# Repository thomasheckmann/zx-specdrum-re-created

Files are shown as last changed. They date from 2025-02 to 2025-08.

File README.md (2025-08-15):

# zx-specdrum-re-created
Recreated and improved version of [Currah SpecDrum](https://spectrumcomputing.co.uk/entry/1000062/Hardware/Cheetah_SpecDrum) Interface for ZX Spectrum

Work on this was initiated because existing schema found on the internet is with errors.

# Version 1
First version is more or less a 1:1 copy of the original interface. With help I got the correct values and type for all the Capacitors. Thanks to Matthew Logue for providing the information from his original interfaces, helping out with how to use the old software as well as doing a test build of the interface.

The only changes compared with original:
* PCB made more compact to fit into my ZX-Bus-Extender board, you can use a normal edge connecter if you prefer.
* Some components moved, all ICs now have the same orientation.
* Make sure all ICs have decoupling capacitors.
* Added a 3.5" mini-jack plug for audio out.

BOM:

## This is how version 1 turned out
| <!---> | <!---> |
| --- | --- |
|||

And it sounds like this in action https://youtube.com/shorts/cKAM5VnGr6U?feature=share

# Version 2
This update fixes a few errors from the initial release and introduces an option for sound enhancement:

* bypassed the anti-aliasing filter and somewhat improved the bass response
* option to switch between original or improved output (using jumper)
* C7 - changed from Ceramic 1uF to Electrolytic 10uF

BOM (recommended order):
* 4 x 6,2K Resistor
* 2 x 10,0K Resistor
* 2 x 100K Resistor
* 1 x 390R Resistor
* 1 x 680R Resistor
* 1 x 390K Resistor

* 3 x 100nF - MLC Capacitor P2,54
* 1 x 1nF - Ceramic Capacitor P2,54

* 1 x 2,7nF - Ceramic Capacitor P2,54
* 1 x 2,2nF - Ceramic Capacitor P2,54
* 1 x 82pF - Ceramic NPO P5,08

* 3 x 1uF - Tantal P5,08
* 1 x 22uF - Electrolyte Capacitor P2,54
* 1 x 10uF - Electrolyte Capacitor P2,54

* 1 x 74LS32
* 1 x TL084
* 1 x ZN428E-8
* 3.5 mono jack [like this](https://elektronik-lavpris.dk/p136328/pj-211-35mm-mono-jack-chassis-med-afbryder-switch/)

The sound improvement modification was suggested by D.A. Wilson of Hideaway Studio and is used here with permission. You can read about the mod [here](https://spectrumcomputing.co.uk/forums/viewtopic.php?t=4845)

## Version v1.2
[Hear the interface](https://youtube.com/shorts/OHfJIYJJYTI) in action here, playing a demo from the original [software](https://spectrumcomputing.co.uk/entry/8720/ZX-Spectrum/SpecDrum)

| <!---> | <!---> |
| --- | --- |
|||

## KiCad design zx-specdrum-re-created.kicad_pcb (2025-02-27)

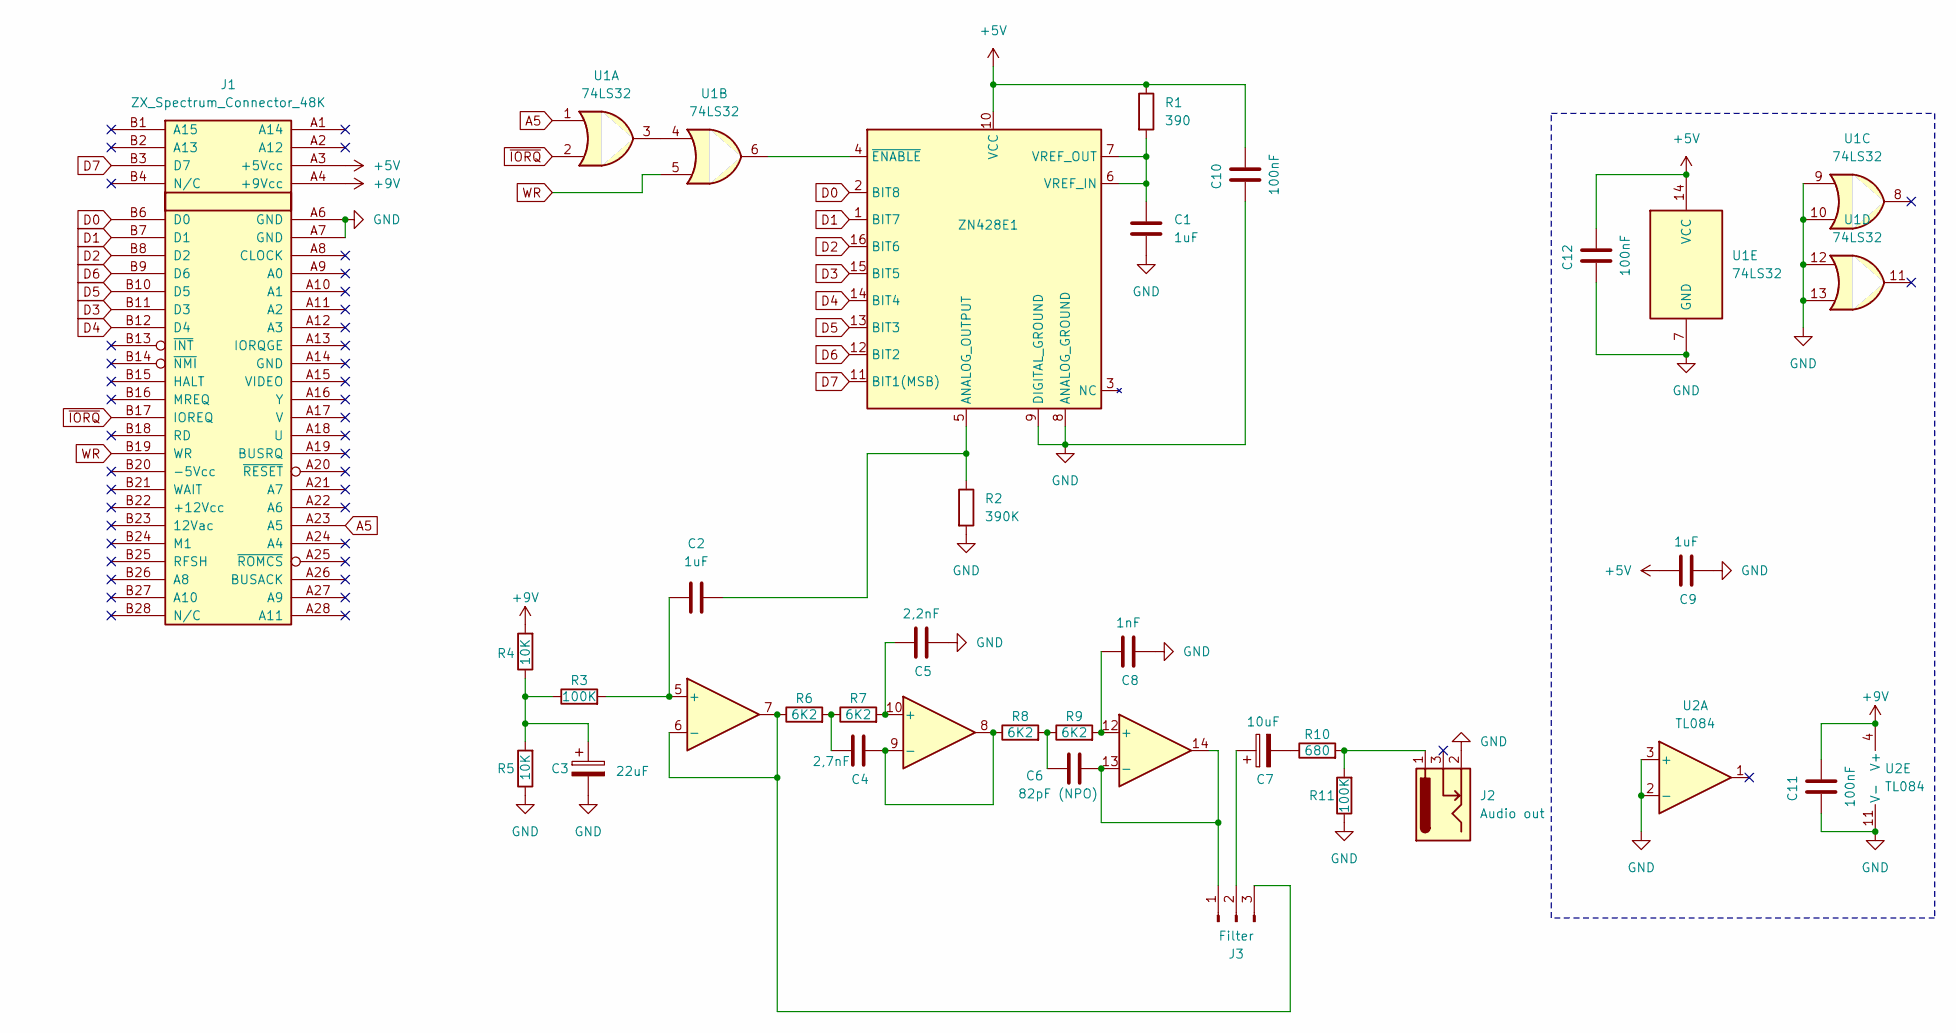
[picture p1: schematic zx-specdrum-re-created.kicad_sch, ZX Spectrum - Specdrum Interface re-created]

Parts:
C1, C2, C9: 1uF; C_Disc_D4.3mm_W1.9mm_P5.00mm
C3: 22uF; CP_Radial_D5.0mm_P2.50mm
C4: 2,7nF; C_Disc_D3.0mm_W1.6mm_P2.50mm
C5: 2,2nF; C_Disc_D3.0mm_W1.6mm_P2.50mm
C6: 82pF (NPO); C_Disc_D4.3mm_W1.9mm_P5.00mm
C7: 10uF; CP_Radial_D5.0mm_P2.50mm
C8: 1nF; C_Disc_D3.0mm_W1.6mm_P2.50mm
C10, C11, C12: 100nF; C_Disc_D3.0mm_W1.6mm_P2.50mm
J1: ZX_Spectrum_Connector_48K; EDGE_ZX_SPECTRUM
J2: Audio out; 3.5mm mono jack chassis with switch
J3: Filter; PinHeader_1x03_P2.54mm_Vertical
R1: 390; R_Axial_DIN0207_L6.3mm_D2.5mm_P10.16mm_Horizontal
R2: 390K; R_Axial_DIN0207_L6.3mm_D2.5mm_P10.16mm_Horizontal
R3, R11: 100K; R_Axial_DIN0207_L6.3mm_D2.5mm_P10.16mm_Horizontal
R4, R5: 10K; R_Axial_DIN0207_L6.3mm_D2.5mm_P10.16mm_Horizontal
R6, R7, R8, R9: 6K2; R_Axial_DIN0207_L6.3mm_D2.5mm_P10.16mm_Horizontal
R10: 680; R_Axial_DIN0207_L6.3mm_D2.5mm_P10.16mm_Horizontal
U1: 74LS32; DIP-14_W7.62mm_Socket
U2: TL084; DIP-14_W7.62mm_Socket
ZN428E1: DIP-16_W7.62mm_Socket

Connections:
+5V: C9.1, C10.1, C12.1, J1.A3 (+5Vcc), R1.1, U1.14 (VCC), ZN428E1.10 (VCC)
+9V: C11.1, J1.A4 (+9Vcc), R4.2, U2.4 (V+)
A5: J1.A23 (A5), U1.1
D0: J1.B6 (D0), ZN428E1.2 (BIT8)
D1: J1.B7 (D1), ZN428E1.1 (BIT7)
D2: J1.B8 (D2), ZN428E1.16 (BIT6)
D3: J1.B11 (D3), ZN428E1.15 (BIT5)
D4: J1.B12 (D4), ZN428E1.14 (BIT4)
D5: J1.B10 (D5), ZN428E1.13 (BIT3)
D6: J1.B9 (D6), ZN428E1.12 (BIT2)
D7: J1.B3 (D7), ZN428E1.11 (BIT1(MSB))
GND: C1.2, C3.2, C5.2, C8.2, C9.2, C10.2, C11.2, C12.2, J1.A6 (GND), J1.A7 (GND), J2.2, R2.2, R5.1, R11.1, U1.7 (GND), U1.9, U1.10, U1.12, U1.13, U2.2 (-), U2.3 (+), U2.11 (V-), ZN428E1.8 (ANALOG_GROUND), ZN428E1.9 (DIGITAL_GROUND)
unnamed: C3.1, R3.1, R4.1, R5.2
unnamed: C4.1, R6.2, R7.1
unnamed: C6.1, R8.2, R9.1
unnamed: C7.2, R10.1
unnamed: J2.1, R10.2, R11.2
unnamed: C6.2, J3.1, U2.13 (-), U2.14
unnamed: C7.1, J3.2
unnamed: J3.3, R6.1, U2.6 (-), U2.7
unnamed: U1.3, U1.4
unnamed: C2.1, R3.2, U2.5 (+)
unnamed: C5.1, R7.2, U2.10 (+)
unnamed: C4.2, R8.1, U2.8, U2.9 (-)
unnamed: C8.1, R9.2, U2.12 (+)
unnamed: C2.2, R2.1, ZN428E1.5 (ANALOG_OUTPUT)
unnamed: C1.1, R1.2, ZN428E1.6 (VREF_IN), ZN428E1.7 (VREF_OUT)
unnamed: U1.6, ZN428E1.4 (~ENABLE)
WR: J1.B19 (WR), U1.5
~IORQ: J1.B17 (IOREQ), U1.2

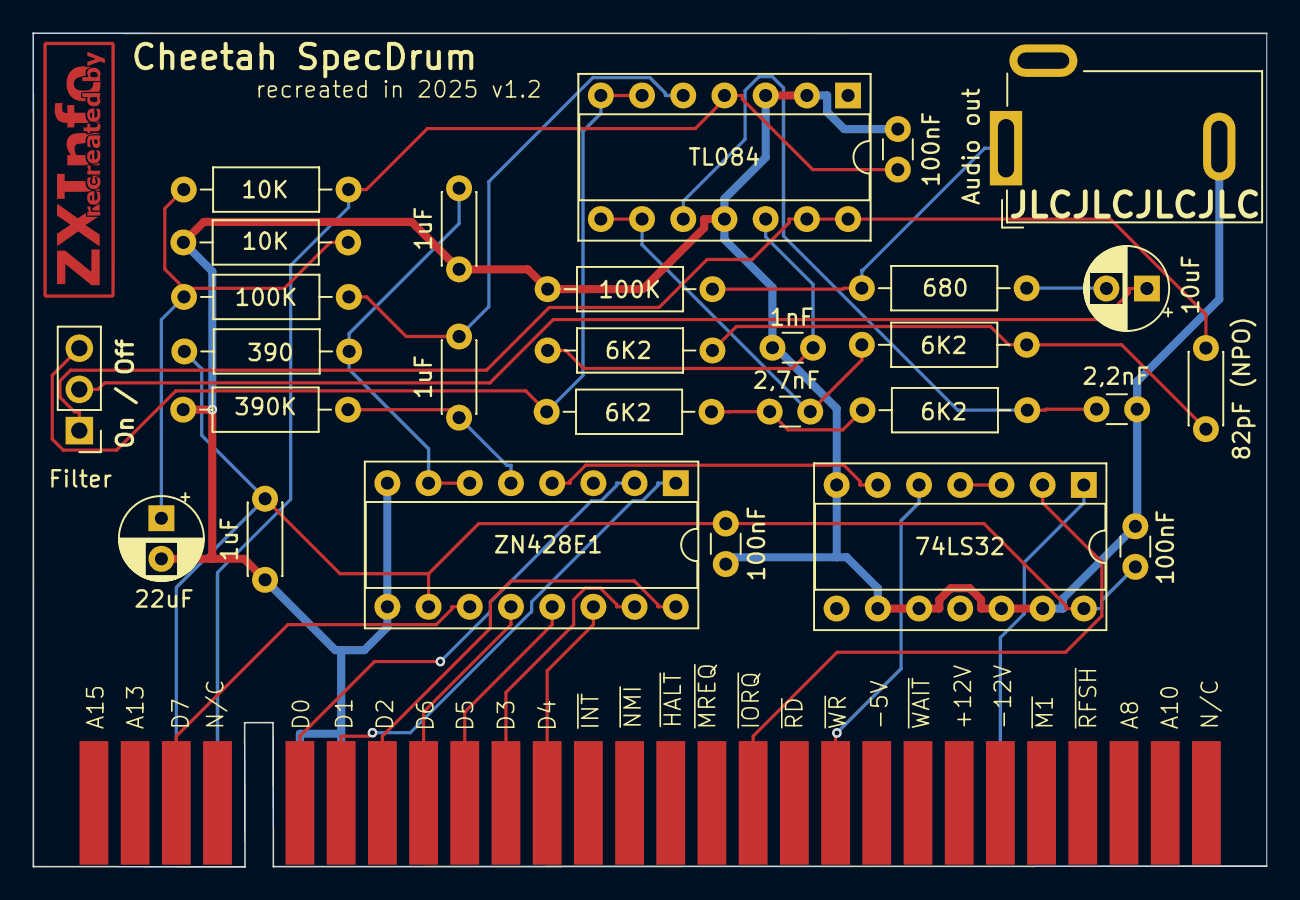
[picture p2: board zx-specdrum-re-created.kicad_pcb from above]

Board: 2 copper layers, 76.0 x 51.4 mm, 30 parts (0 on the bottom side), 30 nets.

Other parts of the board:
G200: LOGO; ZXInfo_kicad_logo_copper_16.5x5

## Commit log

2025-02-27 Intial version
    [zx-specdrum-re-created.kicad_pcb, zx-specdrum-re-created.kicad_sch]
2025-02-27 Version 1.2 update
    [zx-specdrum-re-created.kicad_pcb, zx-specdrum-re-created.kicad_sch]
